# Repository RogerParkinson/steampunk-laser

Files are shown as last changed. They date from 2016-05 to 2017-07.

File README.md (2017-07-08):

# steampunk-laser
Plays a noise on ATTiny85 using tone() PWM pin 4 and flashes a couple of LEDs

This code was loaded into an ATTiny85 that was embedded into a toy pistol with a laser pointer in the tip. When the trigger is pulled the tone sounds and the laser is turned on. There are a couple of blinking LEDs as well.

The finished laser looks like this:

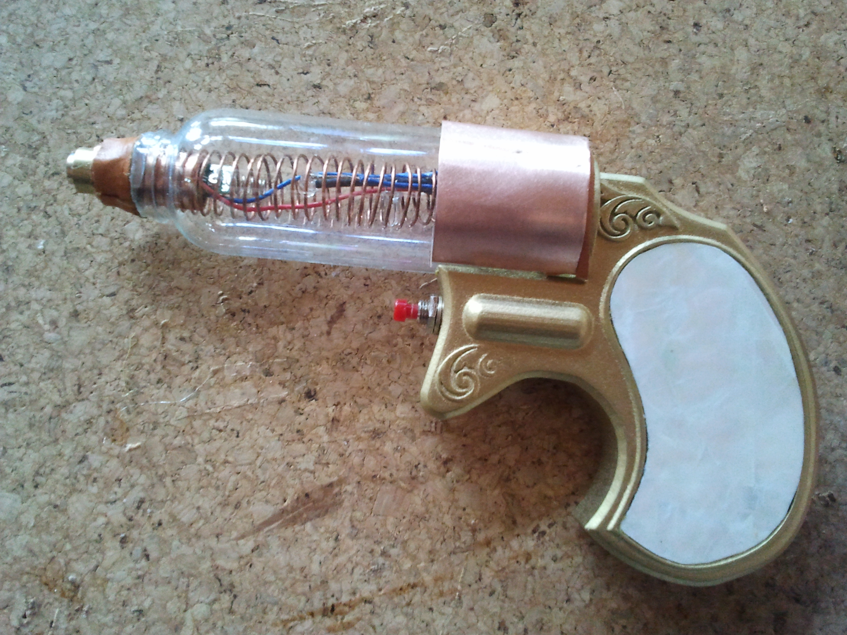
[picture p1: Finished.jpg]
Finished


[video](https://youtu.be/AGKMF4kWh64)

The handle was designed in blender and 3D printed with a spacein it to hold a LIPO battery.
This is the bare handle:

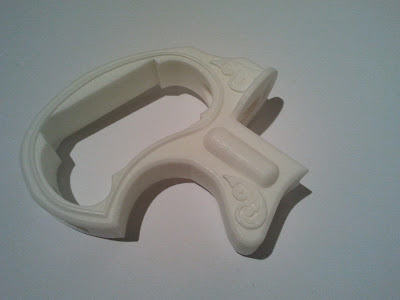
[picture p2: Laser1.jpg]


And this is the handle after painting and covering with fake mother of pearl.

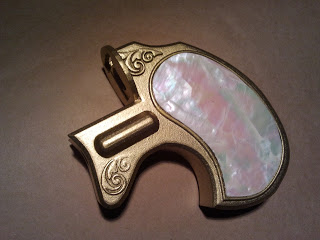
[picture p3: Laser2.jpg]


[video](https://youtu.be/AGKMF4kWh64)

We adapted the idea to make a bird scarer with glowing eyes. Some minor changes to the circuit and the code and it wakes up every 15 minutes to scare swallows that were nesting on the side of a house. The noise was adjusted to sound like a growling animal. THis was powered by 2xAA batteries.
This was, in fact, a total failure. The swallows were initially bothers but in 3 weeks they had built a nest on top of it. The batteries were still going well, attesting to the usefulness of the ATTiny85's sleep function.

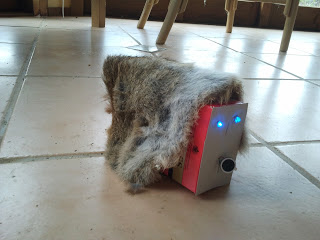
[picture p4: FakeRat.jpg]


The circuit for this is shown here:

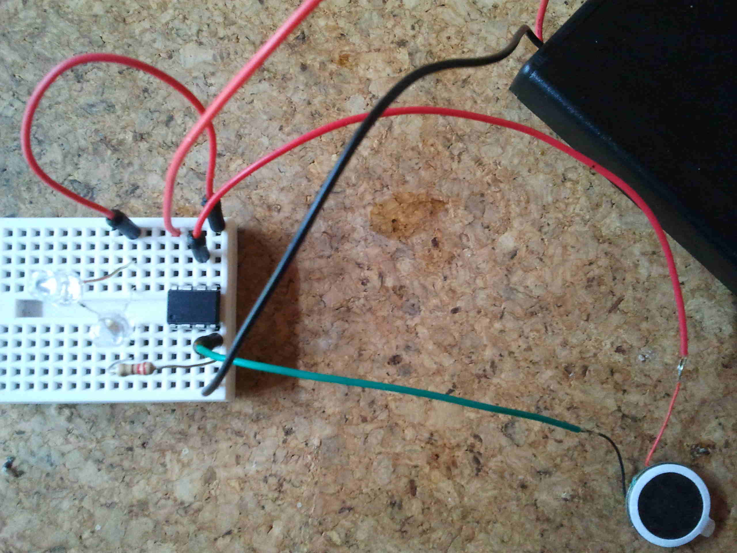
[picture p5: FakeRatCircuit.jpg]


# Building the Software

We used Arduino IDE 1.6.7 with the [arduino-tiny core](https://code.google.com/archive/p/arduino-tiny/). The arduino-tiny-core is necessary for building ATTiny projects.
The Arduino IDE includes a Boards Manager which will install a core for ATTiny boards but this does *not* include the tone function. The code here will build fine under that core
but you will not hear anything from the speaker. However the arduino-tiny-core does not install automatically, you need do download it and unzip. See the readme file in the unzip. 
But even with that we had to edit the platform.txt file to point to the compiler and we had to move the empty85at*.hex files from ~/Arduino/hardware/tiny/avr/bootloader/empty to ~/Arduino/hardware/tiny/avr/bootloader.

To run the build in the IDE you need to pick the *ATtiny85 @ 1 MHz  (internal oscillator; BOD disabled)* board and then run the compile.

To load it into your board you need an [AVR programmer](https://www.sparkfun.com/products/11801).

# Hardware

This is the parts list for the electronics:
DIP
ATTiny85
Diode
Test button
battery
laser
Speaker
the other parts are either easy to find or up to you to chose what you like, eg the trigger we used is a push button that fitted into the handle.

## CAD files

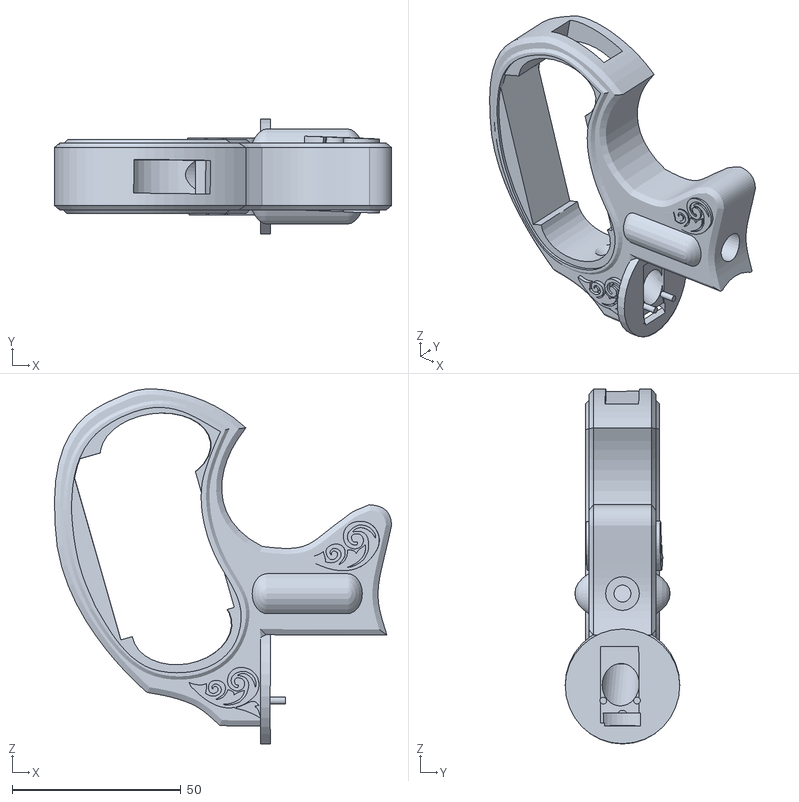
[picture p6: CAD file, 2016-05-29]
handle.stl
100.0 x 34.0 x 105.3

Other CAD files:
handle.blend

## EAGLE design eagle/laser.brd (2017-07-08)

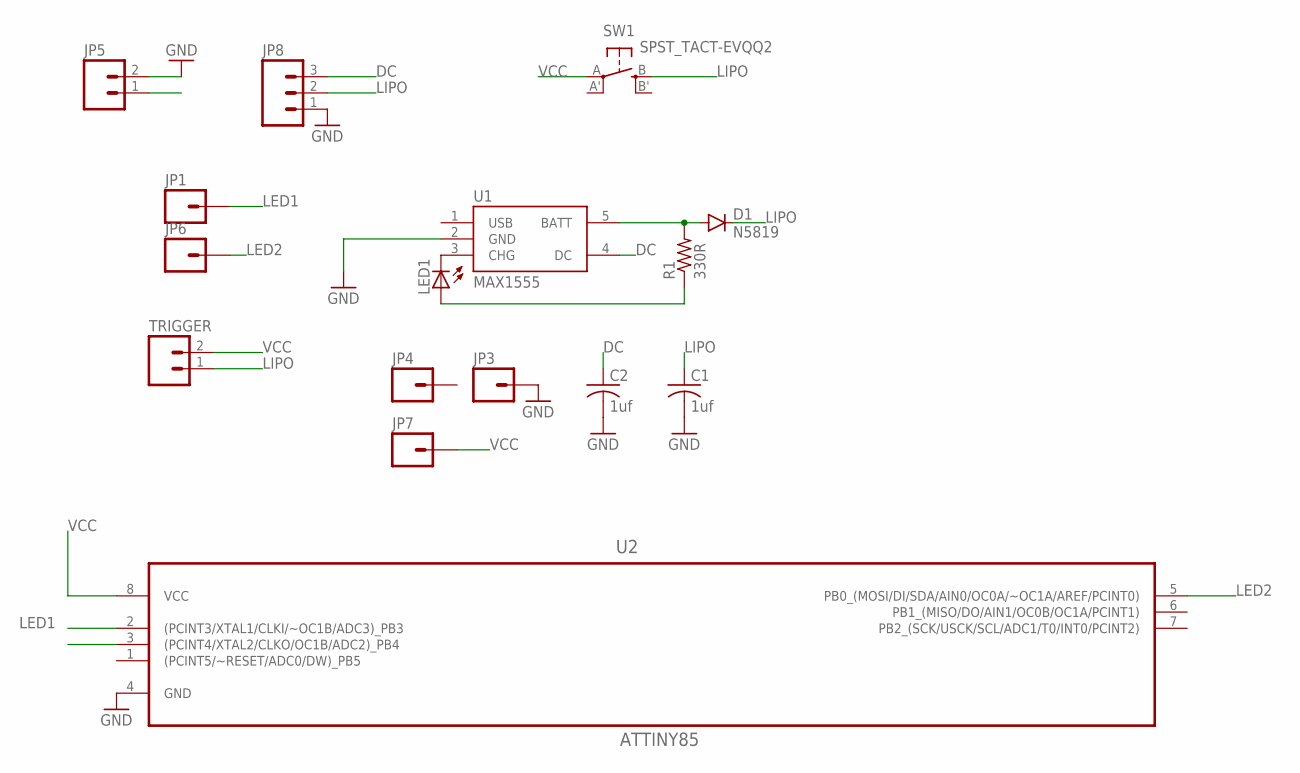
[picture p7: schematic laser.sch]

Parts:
C1, C2: 1uf; C0805K
D1: N5819; DIODE-1N4148
JP1, JP3, JP4, JP6, JP7: M01PTH; 1X01
JP5: M02LOCK; 1X02_LOCK
JP8: M03LOCK; 1X03_LOCK
LED1: LEDCHIP-LED0805; CHIP-LED0805
R1: 330R; M0805
SW1: SPST_TACT-EVQQ2; EVQ-Q2
TRIGGER: M02PTH; 1X02
U1: MAX1555; SOT23-5
U2: ATTINY85; DIP254P762X533-8

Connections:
DC: C2.1, JP8.3, U1.4 (DC)
GND: C1.2, C2.2, JP3.1, JP5.2, JP8.1, U1.2 (GND), U2.4 (GND)
LED1: JP1.1, U2.2 ((PCINT3/XTAL1/CLKI/~OC1B/ADC3)_PB3)
LED2: JP6.1, U2.5 (PB0_(MOSI/DI/SDA/AIN0/OC0A/~OC1A/AREF/P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)
LIPO: C1.1, D1.C, JP8.2, SW1.B (S), TRIGGER.1
unnamed: LED1.C, U1.3 (CHG)
unnamed: D1.A, R1.2, U1.5 (BATT)
unnamed: LED1.A, R1.1
TONE: JP5.1, U2.3 ((PCINT4/XTAL2/CLKO/OC1B/ADC2)_PB4)
VCC: JP7.1, SW1.A, TRIGGER.2, U2.8 (VCC)

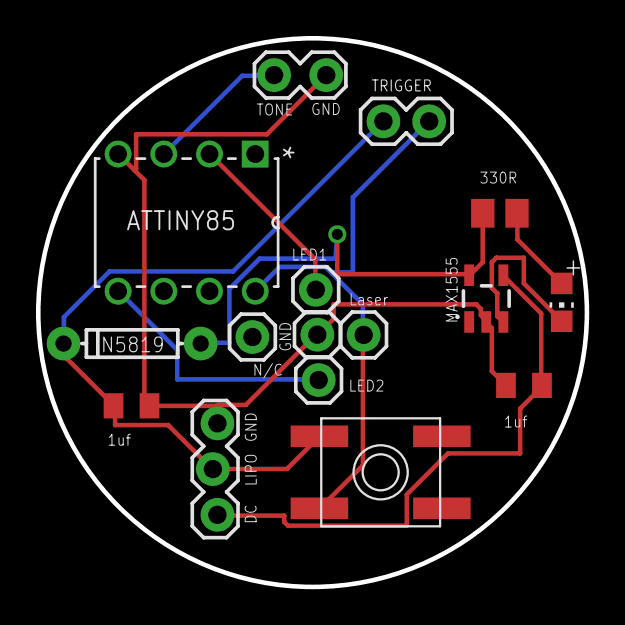
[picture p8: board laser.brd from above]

Board: 2 copper layers, 30.5 x 30.5 mm, 16 parts (0 on the bottom side), 10 nets.

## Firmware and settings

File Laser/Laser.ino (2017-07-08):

// Do not remove the include below
#include "Laser.h"


/*


 Plays a melody on ATTiny85 using tone() PWM pin 4

 circuit:
 * 8-ohm speaker on digital pin 0

 */

#define TONE_PIN 4
#define NOTE_DURATION 1
#define LED_PIN PORTB3
#define LED_PIN1 PORTB0
int LED_cycle=0;


void setup(void);
void loop(void);

void setup() {
  DDRB |= _BV(LED_PIN);
  DDRB |= _BV(LED_PIN1);
  PINB |= _BV(LED_PIN);
  //setupTimer1(myISR);

}
#ifndef ARDUINO                     //main() function not required in Arduino environment
int main(void) {
    setup();
    for(;;) {loop();}
    return 0;
}
#endif
void myISR() {                      //this function will be called every 10ms
    static uint8_t myCounter;

    if (++myCounter == 100) {       //has a second elapsed?
        myCounter = 0;
        PINB |= _BV(LED_PIN);           //toggle the LED
        PINB |= _BV(LED_PIN1);           //toggle the LED
    }
}

void loop() {
  // repeat the melody.
  static uint8_t myCounter;
  if (++myCounter == 100) {       //has a second elapsed?
    myCounter = 0;
    }

  if (myCounter % 1 == 0) {
    PINB |= _BV(LED_PIN);           //toggle the LED
    PINB |= _BV(LED_PIN1);           //toggle the LED
  }

//  digitalWrite(LED_PIN, HIGH);
  for (int thisNote=95; thisNote<105; thisNote++)
  {
    playNote(thisNote,NOTE_DURATION);;
  }
//  digitalWrite(LED_PIN, LOW);
//  digitalWrite(LED_PIN1, HIGH);

  for (int thisNote=105; thisNote>95; thisNote--)
  {
    playNote(thisNote,NOTE_DURATION);
  }
//  digitalWrite(LED_PIN1, LOW);
}

void playNote(int note, int duration)
{
    int noteDuration = 1000/(duration*16);
    tone(TONE_PIN, note,noteDuration);
    int pauseBetweenNotes = noteDuration * 1/4;//1.30;
    delay(pauseBetweenNotes);
    // stop the tone playing:
    noTone(TONE_PIN);

 //   tone(TONE_PIN, 90,noteDuration);
 //   delay(pauseBetweenNotes/4);
    // stop the tone playing:
 //   noTone(TONE_PIN);
 }

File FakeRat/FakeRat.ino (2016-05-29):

// This is probably the correct FakeRat program
// Do not remove the include below
#include "FakeRat.h"
#include <avr/sleep.h>
#include <avr/wdt.h>

#ifndef cbi
#define cbi(sfr, bit) (_SFR_BYTE(sfr) &= ~_BV(bit))
#endif
#ifndef sbi
#define sbi(sfr, bit) (_SFR_BYTE(sfr) |= _BV(bit))
#endif

int timeCount = 9999; // initial high values so it fires on startup
#define LED_PIN 0
#define TONE_PIN 1
volatile boolean f_wdt = 1;

void setup(){
  pinMode(LED_PIN,OUTPUT);
  setup_watchdog(9); // approximately 8 seconds sleep
}
#ifndef ARDUINO                     //main() function not required in Arduino environment
int main(void) {
    setup();
    for(;;) {loop();}
    return 0;
}
#endif

void loop(){
  if (f_wdt==1) {  // wait for timed out watchdog / flag is set when a watchdog timeout occurs
    f_wdt=0;       // reset flag

    if (timeCount++ > 225) // should be 30 mins
    {
		digitalWrite(LED_PIN,HIGH);  // let led on
		tone(TONE_PIN, NOTE_CS4,1000);
		delay(500);
		tone(TONE_PIN, NOTE_FS4,1000);
		delay(500);
		tone(TONE_PIN, NOTE_B0,1000);
		delay(500);
		noTone(TONE_PIN);
		digitalWrite(LED_PIN,LOW); // led off
		timeCount = 0;
    }
    pinMode(LED_PIN,INPUT); // set all used port to input to save power
    pinMode(TONE_PIN,INPUT); // set all used port to input to save power
    system_sleep();
    pinMode(LED_PIN,OUTPUT); // set all ports into state before sleep
    pinMode(TONE_PIN,OUTPUT); // set all ports into state before sleep
  }
}
// set system into the sleep state
// system wakes up when wtchdog is timed out
void system_sleep() {
  cbi(ADCSRA,ADEN);                    // switch Analog to Digitalconverter OFF

  set_sleep_mode(SLEEP_MODE_PWR_DOWN); // sleep mode is set here
  sleep_enable();

  sleep_mode();                        // System sleeps here

  sleep_disable();                     // System continues execution here when watchdog timed out
  sbi(ADCSRA,ADEN);                    // switch Analog to Digitalconverter ON
}

// 0=16ms, 1=32ms,2=64ms,3=128ms,4=250ms,5=500ms
// 6=1 sec,7=2 sec, 8=4 sec, 9= 8sec
void setup_watchdog(int ii) {

  byte bb;
  int ww;
  if (ii > 9 ) ii=9;
  bb=ii & 7;
  if (ii > 7) bb|= (1<<5);
  bb|= (1<<WDCE);
  ww=bb;

  MCUSR &= ~(1<<WDRF);
  // start timed sequence
  WDTCR |= (1<<WDCE) | (1<<WDE);
  // set new watchdog timeout value
  WDTCR = bb;
  WDTCR |= _BV(WDIE);
}

// Watchdog Interrupt Service / is executed when watchdog timed out
ISR(WDT_vect) {
  f_wdt=1;  // set global flag
}

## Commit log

2016-05-29 Reworked project to include FakeRat as well as Laser Also moved it to use Arduino IDE rather than Eclipse (Eclipse is too complicated to sustain)
    [handle.blend, handle.stl]
2017-07-08 Added eagle files and updated description and code
    [laser.brd, laser.sch]

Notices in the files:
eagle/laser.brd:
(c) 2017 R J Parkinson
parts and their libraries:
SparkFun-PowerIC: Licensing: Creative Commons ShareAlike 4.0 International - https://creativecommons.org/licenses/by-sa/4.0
